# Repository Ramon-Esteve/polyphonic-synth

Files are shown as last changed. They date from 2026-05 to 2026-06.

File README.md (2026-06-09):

# DIY Polyphonic Analog Synthesizer

A university project building a polyphonic analog synthesizer from scratch using [mki x es.EDU](https://www.ericasynths.lv/shop/diy-kits-1/mki-x-esedu-diy-system/) module designs and an STM32 Nucleo board as a MIDI-to-CV controller.

The goal is to go from a single voice on a breadboard to a playable multi-voice analog synth controlled via MIDI — while documenting every step of the process.

## What This Project Is

This is an educational build that combines:
- **Analog circuit design** — VCO, VCF, VCA and envelope circuits based on the publicly available Erica Synths / Moritz Klein educational module designs
- **Embedded firmware** — STM32 Nucleo running custom MIDI-to-CV firmware (MIDI parsing, DAC output, voice allocation)
- **System integration** — bridging the digital (MIDI) and analog (CV/gate) worlds to create a playable instrument

All analog circuits are prototyped on breadboard. The Nucleo board handles MIDI input and outputs control voltages (1V/oct pitch CV, gate, and additional CV for filter/PWM) through its DAC and an op-amp scaling stage.

## Current Status

> **Phase 1 — VCO + MIDI pitch control** *(in progress)*

- [x] VCO built and working on breadboard
- [x] VCO on dedicated PCB (`220526_VCO_V2`) — validated and tested under real circuit conditions
- [ ] Nucleo DAC output verified
- [ ] Op-amp CV scaling circuit (0–3.3V → 0–5V)
- [ ] MIDI input (USB or UART @ 31250 baud)
- [ ] MIDI note-to-CV conversion with 1V/oct tracking
- [ ] Gate output
- [ ] Calibration and tuning

## Build Phases

| Phase | Module | Description | Status |
|---|---|---|---|
| 1 | VCO + MIDI-to-CV | Pitch control of a single oscillator via MIDI keyboard | In progress |
| 2 | VCA + Envelope | Amplitude control with gate/envelope from Nucleo | Planned |
| 3 | VCF | Voltage-controlled filter with CV control of cutoff | Planned |
| 4 | Polyphony | Duplicate voice chains, multi-channel DAC, voice allocation | Planned |

## Hardware

- **Microcontroller:** STM32 Nucleo board (<!-- replace with your specific model, e.g. Nucleo-F446RE -->)
- **Analog modules:** Based on mki x es.EDU circuit designs (VCO, VCA, VCF, Envelope)
- **Prototyping:** Breadboard (switched from stripboard after killing two ICs soldering — lesson learned)
- **DAC output stage:** Op-amp scaling circuit to convert Nucleo's 0–3.3V DAC to 0–5V+ for 1V/oct

## VCO V2 — Bring-Up & Verification (June 2026)

The first custom VCO PCB revision (`220526_VCO_V2`, JLCPCB) has passed full bring-up and verification.

**Verified:**
- Power integrity: rails at ±11.8/−11.9 V, both wire-bridged traces (−12V rail, R7 network) confirmed functional (0.4 Ω continuity, voltage-verified under load)
- Full signal chain: saw core → buffer → AC coupling → ×3.13 gain stage → SAW out (~10 Vpp), comparator → divider → PULSE out (8.88 Vpp)
- PWM: full duty sweep functional, clean latch behaviour only at threshold extremes (by design)
- Frequency range: **~5 Hz to ~49.8 kHz** (full audio range + LFO territory)
- **V/oct tracking: ~10 cents over 2 octaves** after trimming ADJ_TUNE1, verified via Voxengo SPAN — better than the breadboard baseline (~14 ct/oct). Residual error will be handled by the planned STM32 autotune routine.

**Known issues → fixed in V0.2:**
- D4 LED footprint connects to the CV summing node instead of the buffered SAW output (not populated on V2)
- Two manufacturing trace defects bridged with wire (new revision removes bridges)
- Expo converter (BC548/BC558 discrete pair) to be replaced with monolithic matched pair (BC847BS) + tempco resistor

Full measurement protocol: [`docs/bringup_vco_v2/bringup_checklist_VCO_V2.md`](docs/bringup_vco_v2/bringup_checklist_VCO_V2.md)
Test equipment: Tektronix 2225, TOOLTOP ET828 Pro, PeakTech 6225A, RME Fireface + Voxengo SPAN

| VCO V2 PCB | Square wave output on scope |
|---|---|
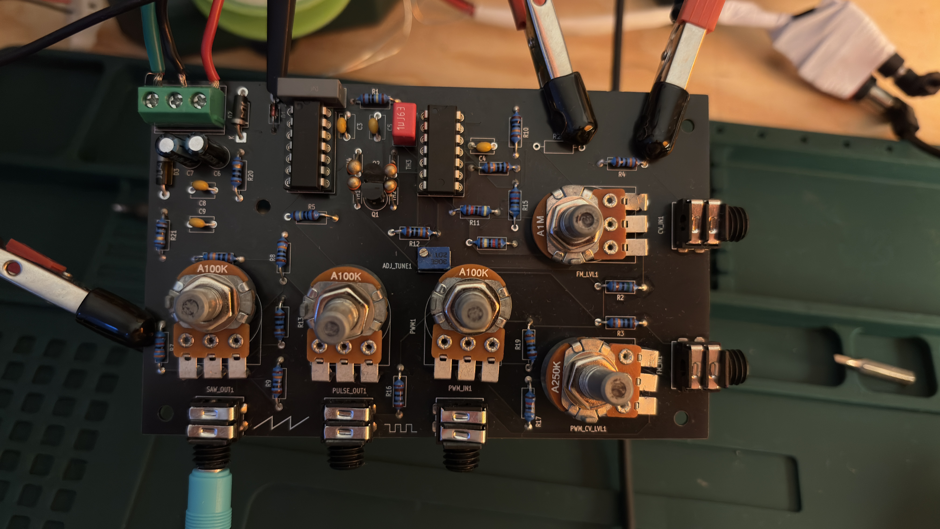
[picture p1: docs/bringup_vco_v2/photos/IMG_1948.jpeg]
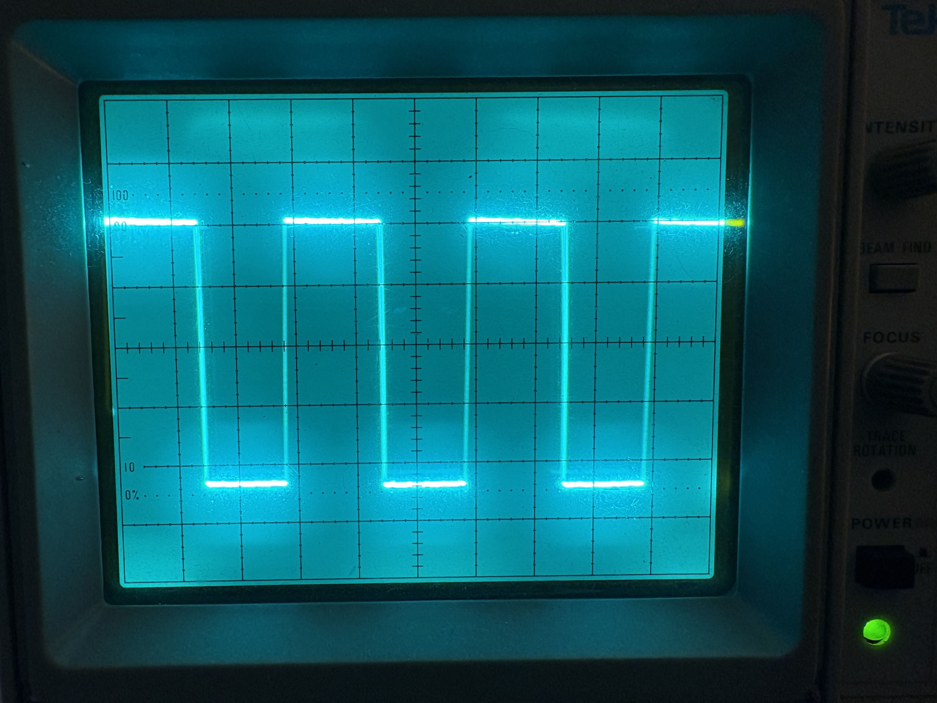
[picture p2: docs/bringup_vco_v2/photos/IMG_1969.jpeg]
|  |  |
## Repository Structure

```
├── docs/                   # Build documentation for each module
├── firmware/               # STM32CubeIDE project — MIDI-to-CV firmware
├── schematics/             # Circuit diagrams and breadboard layouts
├── measurements/           # Tuning data, oscilloscope captures, test results
├── media/                  # Build photos, video material, audio samples
└── references/             # Datasheets, links, related projects
```

## Documentation

Each build phase is documented with:
- Circuit description and design rationale
- Breadboard layout and build notes
- Test procedures and measurements
- Problems encountered and how they were solved

Video documentation accompanies the written docs — see the [media/](media/) folder or the <!-- add link to your YouTube/channel here --> video series.

## Key References

- [mki x es.EDU module manuals](https://www.ericasynths.lv/shop/diy-kits-1/mki-x-esedu-diy-system/) — free PDFs covering circuit design from scratch
- [Moritz Klein's YouTube channel](https://www.youtube.com/@MoritzKlein0) — companion videos to the EDU modules
- [ModSynth MIDI2CV](https://warrantyvoids.github.io/ModSynth/modules/midi2cv/) — STM32 Nucleo-based MIDI-to-CV reference project
- [STM32 DAC getting started](https://wiki.st.com/stm32mcu/wiki/Getting_started_with_DAC) — official ST tutorial

## License

This project is licensed under the MIT License — see [LICENSE](LICENSE) for details.

Note: The analog circuit designs are based on the mki x es.EDU educational series by Erica Synths and Moritz Klein. Their manuals are freely available but the original designs remain their work. This repository contains my own implementation, firmware, documentation, and modifications.

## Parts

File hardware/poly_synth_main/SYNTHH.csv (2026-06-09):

Reference | Qty | Value | DNP | Exclude from BOM | Exclude from Board | Footprint | Datasheet
A1,A2,D17,D21,R42,R135,S1,S2 | 8 | 10k |  |  |  | Potentiometer_THT:Potentiometer_Bourns_PTA6043_Single_Slide
ADJ_TUNE1,ADJ_TUNE2,ADJ_TUNE3 | 3 | 1k |  |  |  | Potentiometer_THT:Potentiometer_Bourns_3266W_Vertical
AUDIO_OUT(3.5mm)1,CV_IN5,FM_IN3,PWM_IN1,PWM_IN2,PWM_IN3 | 6 | AudioJack2_Ground_Switch |  |  |  | AUDIOJACKS:Jack_3.5mm_Cliff_FCR1281_Horizontal
C1,C10,C15 | 3 | 2.2nF |  |  |  | Capacitor_THT:C_Rect_L13.0mm_W4.0mm_P10.00mm_FKS3_FKP3_MKS4
C2,C11,C16 | 3 | 1uF |  |  |  | Capacitor_THT:C_Rect_L7.2mm_W5.0mm_P5.00mm
C3,C4,C5,C8,C9,C12,C13,C14,C17,C18,C19,C20,C21,C28,C29,C31,C32,C35,C36,C37,C38,C39,C40,C41,C42,C43,C44 | 27 | 0.1uF |  |  |  | Capacitor_THT:C_Disc_D5.1mm_W3.2mm_P5.00mm
C6,C7 | 2 | 47uF |  |  |  | Capacitor_THT:C_Radial_D5.0mm_H11.0mm_P2.00mm
C22,C30,C45 | 3 | 1uF
C23,C24,C25,C26,C27 | 5 | 1nF
C33 | 1 | 0.33uF
C34 | 1 | 0.1uF
COARSE1,COARSE2,COARSE3,CUTOFF1,FINE1,FINE2,FINE3,OFFSET1,PWM1,PWM2,PWM3,RESO1,SOFTCLIP1,VCO1,VCO2,VCO3,VCO5,VCO6 | 18 | 100k |  |  |  | Potentiometer_THT:Potentiometer_Omeg_PC16BU_Vertical
D1,D4,D5,D6,D7,D8,D9,D10,D11,D12,D13,D14,D15,D16 | 14 | 1N4148 |  |  |  | Diode_THT:D_DO-35_SOD27_P7.62mm_Horizontal | https://assets.nexperia.com/documents/data-sheet/1N4148_1N4448.pdf
D2,D3,D18,D19,D20 | 5 | SB140 |  |  |  | Diode_THT:D_DO-41_SOD81_P10.16mm_Horizontal | http://www.diodes.com/_files/datasheets/ds23022.pdf
FM_LVL3 | 1 | 1M |  |  |  | Potentiometer_THT:Potentiometer_Omeg_PC16BU_Vertical
J1 | 1 | DC_IN |  |  |  | TerminalBlock_RND:TerminalBlock_RND_205-00288_1x03_P5.08mm_Horizontal
J2 | 1 | USB_B
J3 | 1 | AUDIO_OUT(6.35mm)
PWM_CV_LVL1,PWM_CV_LVL2,PWM_CV_LVL3 | 3 | 250k |  |  |  | Potentiometer_THT:Potentiometer_Omeg_PC16BU_Vertical
Q-Point(Forward_Bias)1,R3,R22,R29,R32,R52,R62,R70,R71,R72,R74,R75,R76,R87,R89,R94,R96,R99,R100,R101,R103,R104,R105,R106,R107,R108,R110,R111,R112,R117,R118,R125,R126,R127,R128,R129,R132,R133,R134,R136,R137 | 41 | 100k
Q1,Q4,Q6,Q7,Q8 | 5 | BC548 |  |  |  | Package_TO_SOT_THT:TO-92_Inline | https://www.onsemi.com/pub/Collateral/BC550-D.pdf
Q2,Q3,Q5 | 3 | BC558 |  |  |  | Package_TO_SOT_THT:TO-92_Inline | https://www.onsemi.com/pub/Collateral/BC556BTA-D.pdf
R1,R5,R27,R31,R47,R51 | 6 | 1M |  |  |  | Resistor_THT:R_Axial_DIN0207_L6.3mm_D2.5mm_P10.16mm_Horizontal
R2,R30,R50 | 3 | 1k5 |  |  |  | Resistor_THT:R_Axial_DIN0207_L6.3mm_D2.5mm_P10.16mm_Horizontal
R4,R6,R8,R9,R10,R12,R14,R19,R23,R25,R26,R28,R33,R34,R38,R39,R43,R45,R46,R48,R49,R53,R54,R58,R59 | 25 | 100k |  |  |  | Resistor_THT:R_Axial_DIN0207_L6.3mm_D2.5mm_P10.16mm_Horizontal
R7,R24,R44 | 3 | 33k |  |  |  | Resistor_THT:R_Axial_DIN0207_L6.3mm_D2.5mm_P10.16mm_Horizontal
R11,R37,R57 | 3 | 47k |  |  |  | Resistor_THT:R_Axial_DIN0207_L6.3mm_D2.5mm_P10.16mm_Horizontal
R13,R16,R41,R63,R64,R65,R66,R67,R68,R69,R114,R138 | 12 | 10k
R15,R17,R35,R40,R55,R60 | 6 | 68k |  |  |  | Resistor_THT:R_Axial_DIN0207_L6.3mm_D2.5mm_P10.16mm_Horizontal
R18,R36,R56 | 3 | 14k |  |  |  | Resistor_THT:R_Axial_DIN0207_L6.3mm_D2.5mm_P10.16mm_Horizontal
R20,R21 | 2 | 10 |  |  |  | Resistor_THT:R_Axial_DIN0207_L6.3mm_D2.5mm_P10.16mm_Horizontal
R61,R78,R79,R81,R82,R83,R84,R85,R93 | 9 | 33k
R73,R86 | 2 | 27k
R77,R80 | 2 | 2k
R88 | 1 | 14k
R90,R91 | 2 | 68k
R92,R95,R97,R130,R131 | 5 | 1k
R98,R102,R109,R113,R123 | 5 | 150k
R115,R116 | 2 | 20k_Matched
R119,R120 | 2 | 10k_MATCHED
R121,R122 | 2 | 100k_MATCHED
R124 | 1 | 100
reso_intensity1 | 1 | 50k |  |  |  | Potentiometer_THT:Potentiometer_Omeg_PC16BU_Vertical
RV1 | 1 | 20k
R_pull_UP_SCL1,R_pull_UP_SDA1 | 2 | 4.7k
SW1,SW3,SW5 | 3 | SAW |  |  |  | Button_Switch_SMD:Nidec_Copal_CAS-120A | https://www.nidec-components.com/e/catalog/switch/cas.pdf
SW2,SW4,SW6 | 3 | PULSE |  |  |  | Button_Switch_SMD:Nidec_Copal_CAS-120A | https://www.nidec-components.com/e/catalog/switch/cas.pdf
SW7 | 1 | SUB |  |  |  | Button_Switch_SMD:Nidec_Copal_CAS-120A | https://www.nidec-components.com/e/catalog/switch/cas.pdf
TH2,TH3,TH4,TH5,TH6,TH7,TH9,TH10,TH11,TH12 | 10 | 10k |  |  |  | Resistor_THT:R_Axial_DIN0204_L3.6mm_D1.6mm_P5.08mm_Horizontal
U1 | 1 | 40106 |  |  |  | Package_DIP:DIP-14_W7.62mm_Socket | https://assets.nexperia.com/documents/data-sheet/HEF40106B.pdf
U2,U4,U6 | 3 | TL074 |  |  |  | Package_DIP:DIP-14_W7.62mm_Socket | http://www.ti.com/lit/ds/symlink/tl071.pdf
U3,U5,U7,U8,U11,U13,U14,U15,U17 | 9 | TL074 |  |  |  |  | http://www.ti.com/lit/ds/symlink/tl071.pdf
U9 | 1 | NUCLEO-F446RE |  |  |  | STM32:MODULE_NUCLEO-F446RE
U10 | 1 | L7805 |  |  |  |  | http://www.st.com/content/ccc/resource/technical/document/datasheet/41/4f/b3/b0/12/d4/47/88/CD00000444.pdf/files/CD00000444.pdf/jcr:content/translations/en.CD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
U12 | 1 | MCP4728 |  |  |  | Package_SO:MSOP-10_3x3mm_P0.5mm | http://ww1.microchip.com/downloads/en/DeviceDoc/22187E.pdf
U16 | 1 | ER_OLEDM0.91_1x-I2C |  |  |  | Display:ER_OLEDM0.91_1x-I2C | https://www.buydisplay.com/download/manual/ER-OLEDM0.91-1_Datasheet.pdf

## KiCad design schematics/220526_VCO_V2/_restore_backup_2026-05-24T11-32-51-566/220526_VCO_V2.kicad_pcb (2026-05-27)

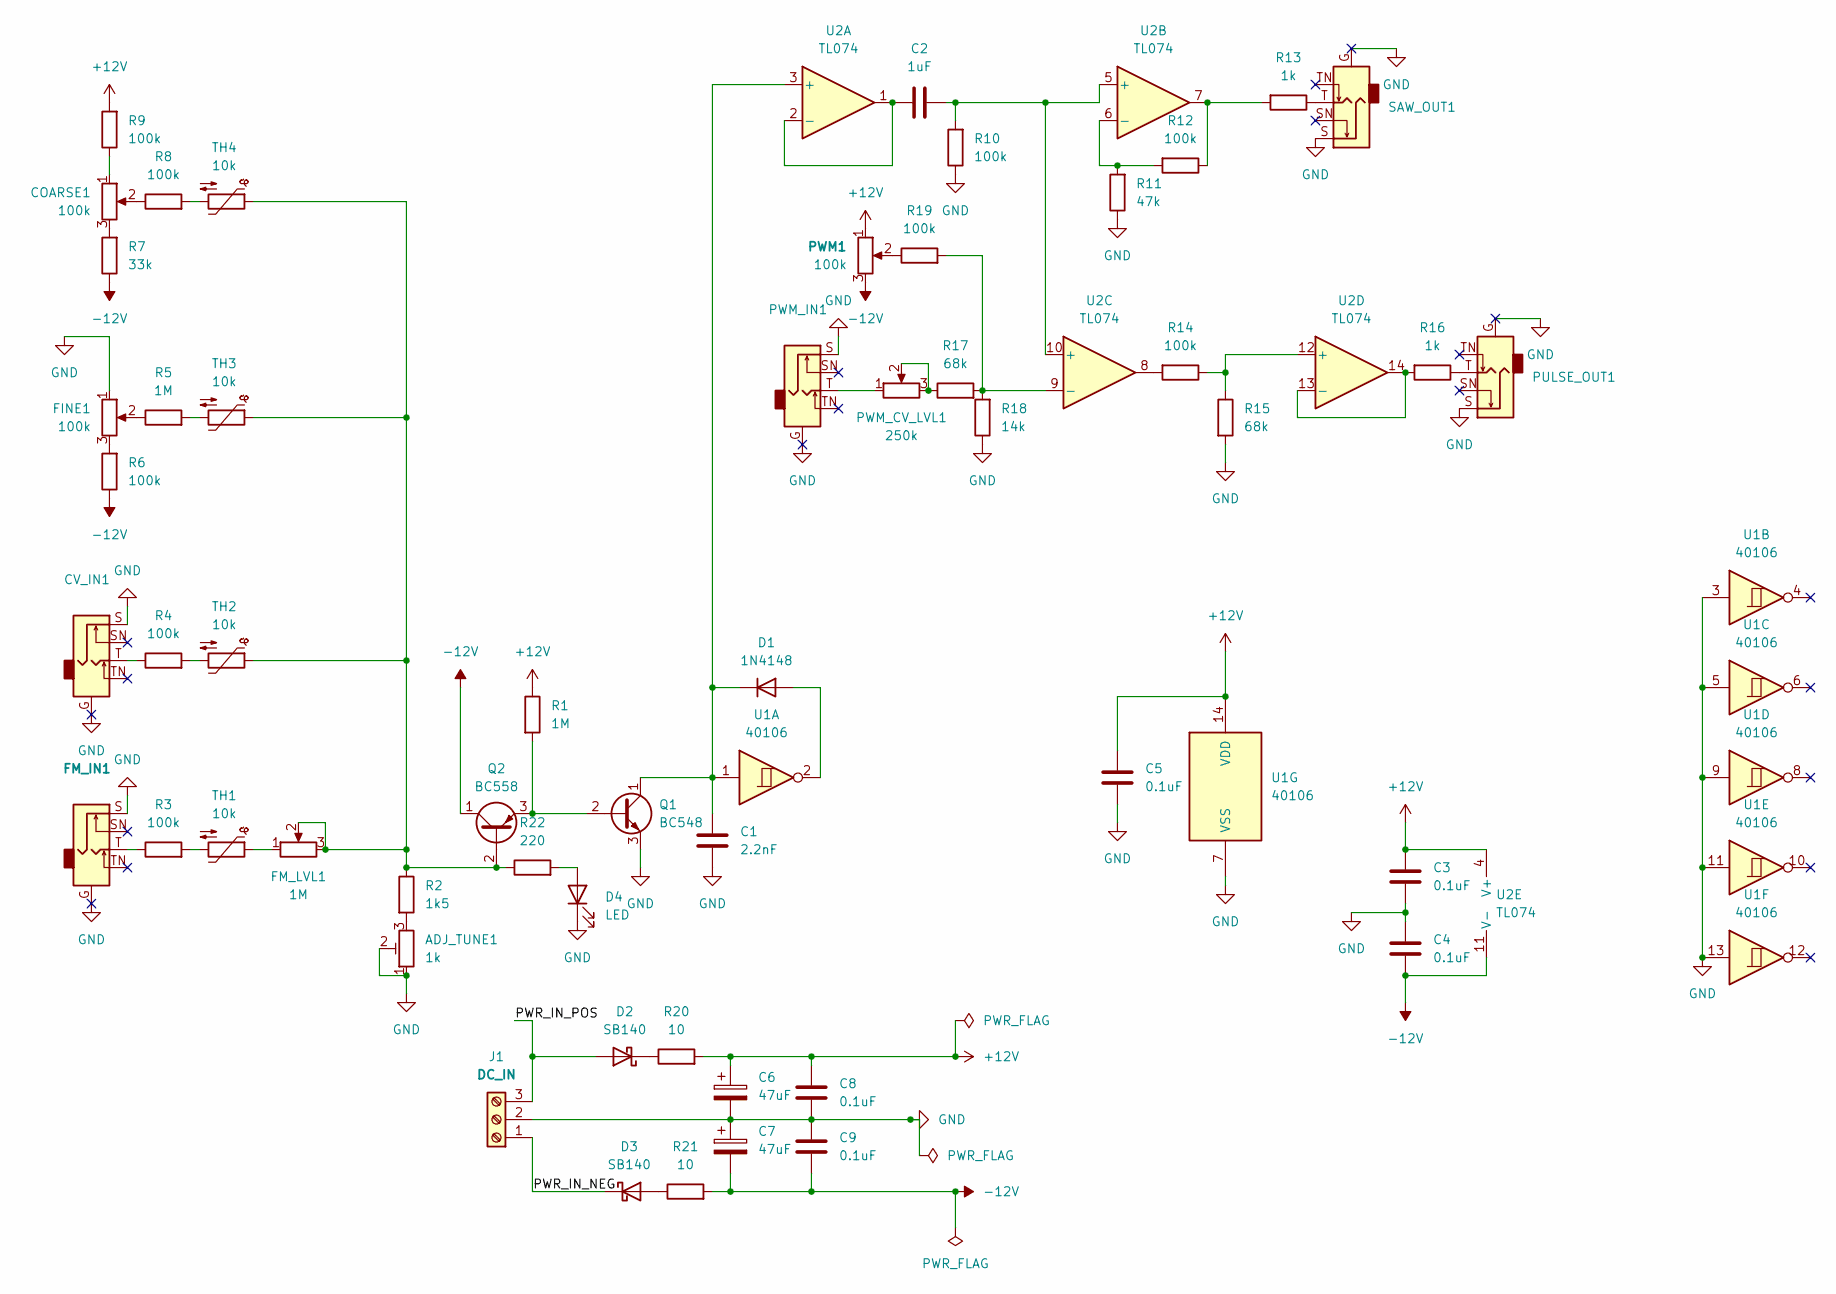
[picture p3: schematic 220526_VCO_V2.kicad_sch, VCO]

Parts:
ADJ_TUNE1: 1k; Potentiometer_Bourns_3266W_Vertical
C1: 2.2nF; C_Rect_L13.0mm_W4.0mm_P10.00mm_FKS3_FKP3_MKS4
C2: 1uF; C_Rect_L7.2mm_W5.0mm_P5.00mm
C3, C4, C5, C8, C9: 0.1uF; C_Disc_D5.1mm_W3.2mm_P5.00mm
C6, C7: 47uF; C_Radial_D5.0mm_H11.0mm_P2.00mm
COARSE1: 100k; Potentiometer_Omeg_PC16BU_Vertical
CV_IN1: AudioJack2_Ground_Switch; Jack_3.5mm_Cliff_FCR1281_Horizontal
D1: 1N4148; D_DO-35_SOD27_P7.62mm_Horizontal
D2, D3: SB140; D_DO-41_SOD81_P10.16mm_Horizontal
D4: LED; LED_D5.0mm
FINE1: 100k; Potentiometer_Omeg_PC16BU_Vertical
FM_IN1: AudioJack2_Ground_Switch; Jack_3.5mm_Cliff_FCR1281_Horizontal
FM_LVL1: 1M; Potentiometer_Omeg_PC16BU_Vertical
J1: DC_IN; TerminalBlock_RND_205-00288_1x03_P5.08mm_Horizontal
PULSE_OUT1: AudioJack2_Ground_Switch; Jack_3.5mm_Cliff_FCR1281_Horizontal
PWM1: 100k; Potentiometer_Omeg_PC16BU_Vertical
PWM_CV_LVL1: 250k; Potentiometer_Omeg_PC16BU_Vertical
PWM_IN1: AudioJack2_Ground_Switch; Jack_3.5mm_Cliff_FCR1281_Horizontal
Q1: BC548; TO-92_Inline
Q2: BC558; TO-92_Inline
R1, R5: 1M; R_Axial_DIN0207_L6.3mm_D2.5mm_P10.16mm_Horizontal
R2: 1k5; R_Axial_DIN0207_L6.3mm_D2.5mm_P10.16mm_Horizontal
R3, R4, R6, R8, R9, R10, R12, R14, R19: 100k; R_Axial_DIN0207_L6.3mm_D2.5mm_P10.16mm_Horizontal
R7: 33k; R_Axial_DIN0207_L6.3mm_D2.5mm_P10.16mm_Horizontal
R11: 47k; R_Axial_DIN0207_L6.3mm_D2.5mm_P10.16mm_Horizontal
R13, R16: 1k; R_Axial_DIN0207_L6.3mm_D2.5mm_P10.16mm_Horizontal
R15, R17: 68k; R_Axial_DIN0207_L6.3mm_D2.5mm_P10.16mm_Horizontal
R18: 14k; R_Axial_DIN0207_L6.3mm_D2.5mm_P10.16mm_Horizontal
R20, R21: 10; R_Axial_DIN0207_L6.3mm_D2.5mm_P10.16mm_Horizontal
R22: 220; R_Axial_DIN0207_L6.3mm_D2.5mm_P10.16mm_Horizontal
SAW_OUT1: AudioJack2_Ground_Switch; Jack_3.5mm_Cliff_FCR1281_Horizontal
TH1, TH2, TH3, TH4: 10k; R_Axial_DIN0204_L3.6mm_D1.6mm_P5.08mm_Horizontal
U1: 40106; DIP-14_W7.62mm_Socket
U2: TL074; DIP-14_W7.62mm_Socket

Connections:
+12V: C3.1, C5.1, C6.1, C8.1, PWM1.1, R1.1, R9.2, R20.2, U1.14 (VDD), U2.4 (V+)
-12V: C4.2, C7.2, C9.2, PWM1.3, Q2.1 (C), R6.1, R7.1, R21.2, U2.11 (V-)
/PWR_IN_NEG: D3.1 (K), J1.1
/PWR_IN_POS: D2.2 (A), J1.3
GND: ADJ_TUNE1.1, ADJ_TUNE1.2, C1.2, C3.2, C4.1, C5.2, C6.2, C7.1, C8.2, C9.1, CV_IN1.G, CV_IN1.S, D4.1 (K), FINE1.1, FM_IN1.G, FM_IN1.S, J1.2, PULSE_OUT1.G, PULSE_OUT1.S, PWM_IN1.G, PWM_IN1.S, Q1.3 (E), R10.1, R11.1, R15.2, R18.1, SAW_OUT1.G, SAW_OUT1.S, U1.3, U1.5, U1.7 (VSS), U1.9, U1.11, U1.13
unnamed: ADJ_TUNE1.3, R2.2
unnamed: COARSE1.1, R9.1
unnamed: COARSE1.2, R8.1
unnamed: COARSE1.3, R7.2
unnamed: CV_IN1.T, R4.1
unnamed: D1.2 (A), U1.2
unnamed: C1.1, D1.1 (K), Q1.1 (C), U1.1, U2.3 (+)
unnamed: D2.1 (K), R20.1
unnamed: D3.2 (A), R21.1
unnamed: D4.2 (A), R22.2
unnamed: FINE1.2, R5.1
unnamed: FINE1.3, R6.2
unnamed: FM_IN1.T, R3.1
unnamed: FM_LVL1.1, TH1.1
unnamed: PULSE_OUT1.T, R16.1
unnamed: PWM1.2, R19.1
unnamed: PWM_CV_LVL1.1, PWM_IN1.T
unnamed: PWM_CV_LVL1.2, PWM_CV_LVL1.3, R17.1
unnamed: Q1.2 (B), Q2.3 (E), R1.2
unnamed: FM_LVL1.2, FM_LVL1.3, Q2.2 (B), R2.1, R22.1, TH2.1, TH3.1, TH4.1
unnamed: R3.2, TH1.2
unnamed: R4.2, TH2.2
unnamed: R5.2, TH3.2
unnamed: R8.2, TH4.2
unnamed: R12.1, R13.2, U2.7
unnamed: R13.1, SAW_OUT1.T
unnamed: R14.2, U2.8
unnamed: C2.1, U2.1, U2.2 (-)
unnamed: C2.2, R10.2, U2.5 (+), U2.10 (+)
unnamed: R11.2, R12.2, U2.6 (-)
unnamed: R17.2, R18.2, R19.2, U2.9 (-)
unnamed: R14.1, R15.1, U2.12 (+)
unnamed: R16.2, U2.13 (-), U2.14

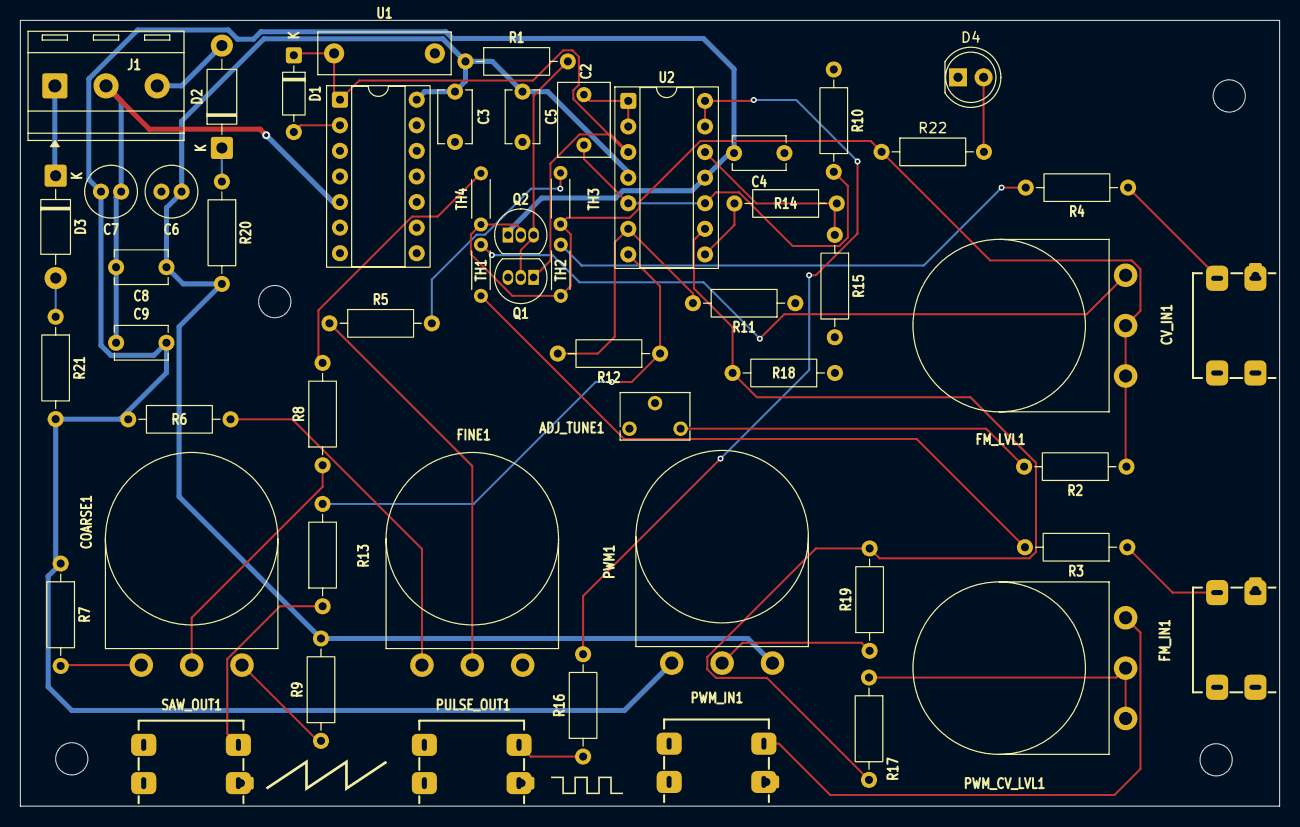
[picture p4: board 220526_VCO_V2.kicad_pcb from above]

Board: 2 copper layers, 125.0 x 78.0 mm, 55 parts (0 on the bottom side), 38 nets.

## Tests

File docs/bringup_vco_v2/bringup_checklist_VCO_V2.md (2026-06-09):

# VCO V2 — Bring-Up & Verification Checklist

Board: `220526_VCO_V2` · Rev: V2 (JLCPCB) · Date: ______ · Ambient: ______ °C
Equipment: Tektronix 2225 (analog, 10× probe — compensate at PRB ADJ first), TOOLTOP ET828 Pro (DMM + Hz/duty). V/oct reference: Fireface + SPAN/Bitwig tuner.

Known issues this revision: wire bridge on −12V rail, wire bridge on R7 network, D4 LED not populated (to be added in V0.2 with dedicated driver off buffered SAW output).

---

## Phase 0 — Unpowered checks (DMM)

| # | Check | Where | Expected | Measured | OK |
|---|---|---|---|---|----|
| 0.1 | +12V ↔ GND resistance | J1 pin 3 ↔ pin 2 | kΩ-range, climbing (caps) | 190 kΩ climbing | ✓ |
| 0.2 | −12V ↔ GND resistance | J1 pin 1 ↔ pin 2 | kΩ-range, climbing | 190 kΩ climbing | ✓ |
| 0.3 | +12V ↔ −12V resistance | J1 pin 3 ↔ pin 1 | no short | 250 kΩ climbing | ✓ |
| 0.4 | −12V bridge continuity | J1 pin 1 → D3-K → R21 → U2 pin 11, C7, C4, C9 | beep, stable under wiggle | ✓ | ✓ |
| 0.5 | R7 bridge continuity | −12V rail → R7 pad 1 → COARSE1 pad 3 | beep, stable under wiggle | ✓ | ✓ |
| 0.6 | GND integrity | J1 pin 2 → U1 pin 7, U2 GND refs, all jack sleeves | beep | ✓ | ✓ |
| 0.7 | D2 diode check (fwd) | A → K | ~0.2–0.4 V | 0.193 V | ✓ |
| 0.8 | D3 diode check (fwd) | A → K | ~0.2–0.4 V | 0.193 V | ✓ |

> Note: D2/D3 are SB140 Schottky — 0.193 V forward drop is correct for this type.

## Phase 1 — First power, rails only (DMM, no patch cables)

| # | Check | Where | Expected | Measured | OK |
|---|---|---|---|---|----|
| 1.1 | +12V rail | U2 pin 4 vs GND | ~+11.4…+11.6 V | +11.83 V | ✓ |
| 1.2 | −12V rail | U2 pin 11 vs GND | ~−11.4…−11.6 V | −11.92 V | ✓ |
| 1.3 | −12V at far end of bridge | C9 pad 2 vs GND | = 1.2 ± 10 mV | −11.92 V | ✓ |
| 1.4 | U1 supply | U1 pin 14 vs pin 7 | ~+11.5 V | +11.83 V | ✓ |
| 1.5 | Drop across R20 | both pads | < 0.3 V | 23.6 mV | ✓ |
| 1.6 | Drop across R21 | both pads | < 0.3 V | 92 mV | ✓ * |
| 1.7 | Thermal check | all ICs, transistors, 1 min | nothing warm | pass | ✓ |

> \* 1.6 asymmetry vs 1.5 (factor ~4): attributable to TL074 output-stage sink current returning via V−. Both values well within acceptable range. Monitor in V0.2 with matched layout.
> Note: 1.3 initially read 337 mV due to probing wrong pad. Re-measured correctly at C9 pad 2 = −11.92 V, confirmed by resistance check U2 pin 11 ↔ C9 pad 2 = 0.4 Ω. No fault.

## Phase 2 — DC operating points (DMM)

| # | Node | Where to probe | Expected | Measured | OK |
|---|---|---|---|---|----|
| 2.1 | COARSE ref range (R7 network) | COARSE1 pad 3 | −6…−9 V (load-dependent) | −6.8 … −8.6 V | ✓ |
| 2.2 | COARSE top ref | COARSE1 pad 1 | ~+1.5…+2.5 V | +2.4 … +1.01 V | ✓ |
| 2.3 | FINE bottom ref | FINE1 pad 3 | ≈ −6 V | −5.7 V | ✓ |
| 2.4 | CV summing node | Q2 base (pad 2) vs GND | sub-volt, moves with COARSE | 19.5 mV | ✓ |
| 2.5 | Expo drive | Q1 base (pad 2) vs GND | ~0.35–0.6 V while oscillating | 512 mV | ✓ |
| 2.6 | LED node | D4 | not populated in this revision | — | — |

> Note: 2.1/2.2 vary with wiper position due to loading of CV summing network — correct behaviour. R7 bridge confirmed functional via voltage range and 0.4 Ω continuity check.

## Phase 3 — Signal chain (scope, 10×, DC coupling unless noted)

Probe ground to any jack sleeve or J1 pin 2. Tek 2225 (analog): document each row with an iPhone photo of the CRT. Amplitude = divisions × V/div × 10 (probe). V/div and s/div settings read from scope panel photos.

| # | Stage | Probe at | V/div (panel) | s/div | Vpp (calculated) | f (calculated) | Photo refs | OK |
|---|---|---|---|---|---|---|---|----|
| 3.1 | Saw core | C1 pad 1 (= D1-K, Q1-C, U1 pin 1) | 1V (×10=10V) | 0.5ms | ~8 Vpp | ~800 Hz | IMG_1948 (probe), IMG_1949 (CRT), IMG_1950 (settings) | ✓ |
| 3.2 | Core buffer | U2 pin 1 | — | — | = 3.1 | = 3.1 | (not separately photographed — identical to 3.1) | ✓ |
| 3.3 | AC-coupled saw | U2 pin 5 | 1V (×10=10V) | 0.5ms | ~8 Vpp, 0V centered | ~800 Hz | IMG_1952 | ✓ |
| 3.4 | Amplified saw | U2 pin 7 | 1V (×10=10V) | 0.5ms | ~9–10 Vpp | ~800 Hz | IMG_1953 (probe), IMG_1954 (CRT) | ✓ |
| 3.5 | SAW output | SAW_OUT1 tip (after R13) | 1V (×10=10V) | 0.5ms | ~9–10 Vpp | ~800 Hz | IMG_1974 (CRT) | ✓ |
| 3.6 | Comparator out | U2 pin 8 | 5V (×10=50V) | 0.2ms | ~21–22 Vpp | ~800 Hz | IMG_1955 (probe), IMG_1960 (CRT) | ✓ |
| 3.7 | Pulse output | PULSE_OUT1 tip (after R16) | 5V (×10=50V) | 0.2ms | 8.88 Vpp | 1.65 kHz | IMG_1965 (ET828) | ✓ |
| 3.8 | PWM sweep | U2 pin 8 / PULSE_OUT while turning PWM1 | 5V | 0.2ms | — | — | IMG_1962 (~30% duty), IMG_1960 (~50%), IMG_1978 (~70%), IMG_1976 (PWM=0, latched) | ✓ |
| 3.9 | Saw reset edge | C1 pad 1, fast timebase | — | — | small overshoot at top, clean fall | — | IMG_1966 (ET828 AC, shark-fin at low f) | ✓ * |
| 3.10 | Frequency range | ET828 Hz on PULSE_OUT, COARSE min→max | — | — | — | f_min ≈ 5.19 Hz / f_max ≈ 49.8 kHz | IMG_1966 (f_min), IMG_1968/1969/1972 (f_max) | ✓ |

> \* 3.9 Reset edge: small overshoot spike visible at reset point on Tek (IMG_1974 top of ramp). Normal for TL074 output stage. No sustained ringing observed. AC-coupled shot at 5 Hz shows shark-fin distortion — expected, capacitor discharge effect at sub-audio frequencies, not a circuit fault.
> Note: ET828 AC-mode Vpp at 5 Hz (14.4 Vpp) is unreliable — well outside the instrument's linear frequency response. Tek measurement (DC-coupled, ~9–10 Vpp) is authoritative.

## Phase 4 — V/oct verification

Feed known CVs into CV_IN1 (MCP4728 chain or precision source). Measure frequency via Fireface + Voxengo SPAN (or Bitwig tuner) — far more accurate than graticule counting on the 2225. ET828 Hz mode (~±1 % rdg ≈ tens of cents) only for f_min/f_max and relative drift, not the cents table.

| CV (V) | f expected (Hz) | f measured (Hz) | Error (cents) |
|---|---|---|---|
| 0 | | | |
| 1 | | | |
| 2 | | | |
| 3 | | | |
| 4 | | | |

- ADJ_TUNE1: set and locked. Tracking verified over 2 octaves via Fireface + Voxengo SPAN.
- **Result: ~10 cents total over 2 octaves (≈5 ct/oct)** — better than breadboard baseline (~14 ct/oct). Remaining error to be handled by STM32 autotune (Timer Input Capture → DAC correction). SPAN screenshots pending.
- Drift test: fixed CV, log f at t=0 / 5 / 10 / 20 min → tempco data for BC847BS redesign justification.

| t (min) | f (Hz) | Ambient (°C) |
|---|---|---|
| 0 | | |
| 5 | | |
| 10 | | |
| 20 | | |

## Phase 5 — Known issues / revision notes

- [x] −12V bridge: continuity confirmed (0.4 Ω, U2 pin 11 ↔ C9 pad 2). Photos: IMG_1951 (PCB back / solder side).
- [x] R7 bridge: COARSE1 pad 3 voltage range −6.8…−8.6 V confirms function.
- [x] Frequency range confirmed: f_min ≈ 5 Hz, f_max ≈ 49.8 kHz. Full usable audio range covered.
- [x] PWM sweep: full duty range functional, latches only at PWM=0 (threshold outside ±1.5V window — correct behaviour).
- [ ] D4 LED: not populated. V0.2: drive from buffered SAW output with series resistor, remove R22 from CV summing node.
- [ ] Expo converter: NPN/PNP (Q1/Q2) drift data to be collected in Phase 4. V0.2: monolithic matched pair (BC847BS) + tempco resistor.
- [x] V/oct tracking trimmed: ~10 ct over 2 octaves, SPAN-verified. Photos pending.
- [ ] Drift test (tempco data for BC847BS redesign) pending
- [ ] Flux cleaned around Q1/Q2/thermistor area (TH1–TH4)

---

**Sign-off:** Board functional ✓ · Calibrated ✓ (10 ct / 2 oct) · Documented ☐ (SPAN photos pending)

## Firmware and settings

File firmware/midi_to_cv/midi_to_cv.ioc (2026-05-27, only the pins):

Mcu.UserName=STM32F446RETx
PA11.Signal=USB_OTG_FS_DM
PA12.Signal=USB_OTG_FS_DP
PA13.GPIO_Label=TMS
PA13.Signal=SYS_JTMS-SWDIO
PA14.GPIO_Label=TCK
PA14.Signal=SYS_JTCK-SWCLK
PA2.GPIO_Label=USART_TX
PA2.Signal=USART2_TX
PA3.GPIO_Label=USART_RX
PA3.Signal=USART2_RX
PA5.GPIO_Label=LD2 [Green Led]
PA5.Signal=GPIO_Output
PB3.GPIO_Label=SWO
PB3.Signal=SYS_JTDO-SWO
PC13.GPIO_Label=B1 [Blue PushButton]
PC13.Signal=GPXTI13
PC14-OSC32_IN.Signal=RCC_OSC32_IN
PC15-OSC32_OUT.Signal=RCC_OSC32_OUT
PH0-OSC_IN.Signal=RCC_OSC_IN
PH1-OSC_OUT.Signal=RCC_OSC_OUT

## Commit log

2026-05-27 add VCO schematic and gerbers
    [220526_VCO_V2-B_Cu.gbr, 220526_VCO_V2-B_Mask.gbr, 220526_VCO_V2-B_Paste.gbr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]
2026-06-09 feat(hardware): add poly synth main board KiCad schematic
    Initial commit of 020623_SYNTH KiCad 10 project.
    Top-level schematic for the paraphonic synthesizer —
    VCOs, VCF, VCA, MIDI-CV, power supply sections.
    [SYNTHH.csv, SYNTHH.kicad_sch]
2026-06-09 docs(hardware): VCO V2 bring-up protocol, photos and README update
    - Full measurement checklist: power integrity, DC operating points,
    signal chain verification (Phase 0-4)
    - V/oct tracking trimmed to ~10 ct over 2 octaves (SPAN-verified)
    - Frequency range 5 Hz - 49.8 kHz confirmed
    - Scope photos (Tektronix 2225 + TOOLTOP ET828 Pro) linked inline
    - Known issues for V0.2 revision documented
    - .gitignore updated: *.mov, KiCad local files
2026-06-09 docs: update current status — VCO on dedicated PCB
